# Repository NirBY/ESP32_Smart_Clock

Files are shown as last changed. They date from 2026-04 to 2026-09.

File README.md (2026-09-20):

# ESP32 Smart Clock

ESP32 smart clock project with an 8x32 MAX7219 LED matrix, AHT20/BMP280 indoor sensors, an NS4168 I2S audio amplifier module, and Home Assistant control through ESPHome.

For normal use, install the **ESPHome smart clock firmware** from `esphome-smart-clock.yaml`.

## Quick Start

1. Install the tested ESPHome version: `python -m pip install "esphome==2026.9.0"`.
2. Copy `secrets.example.yaml` to `secrets.yaml`.
3. Put your Wi-Fi and ESPHome API key in `secrets.yaml`.
4. Connect the ESP32 with a USB data cable.
5. Compile and upload:

   ```powershell
   cd C:\workspace\esp32_smart_clock
   esphome compile esphome-smart-clock.yaml
   esphome upload esphome-smart-clock.yaml
   ```

6. Add the discovered ESPHome device in Home Assistant.

If upload fails, hold **BOOT** while upload starts, then release **BOOT** when writing begins.

## Recover Wi-Fi from your phone

The clock already includes **ESP32 Smart Clock Fallback**, a password-protected
Wi-Fi hotspot and setup page. No Bluetooth, app, Home Assistant connection, or
USB cable is needed to change the router name/password.

1. Power the clock normally. If its configured Wi-Fi network cannot be reached
   (for example, after changing the router password), wait **90 seconds**.
   The fallback hotspot starts automatically; there is no button to press.
2. On your phone, open **Settings > Wi-Fi** and join
   **ESP32 Smart Clock Fallback**.
3. Enter the hotspot password: the value of `fallback_ap_password` in your
   private `secrets.yaml`. This is separate from your home Wi-Fi password.
   Public release builds use the example value `CHANGE_ME_FALLBACK_AP_PASSWORD`.
4. Accept **Stay connected / Use without Internet** if prompted. If the setup
   page does not open automatically, open **http://192.168.4.1/** in your browser
   (HTTP, not HTTPS). Temporarily turn off mobile data or a VPN if your phone
   keeps routing away from the clock.
5. Select your home **2.4 GHz** Wi-Fi network, or enter its name manually, enter
   its password, and press **Save**. The ESP32 board used here cannot join 5 GHz.
6. Allow the clock to connect, then reconnect your phone to your normal network.
   The fallback hotspot shuts down after connection. If the password is wrong,
   reconnect to the fallback hotspot and try again.

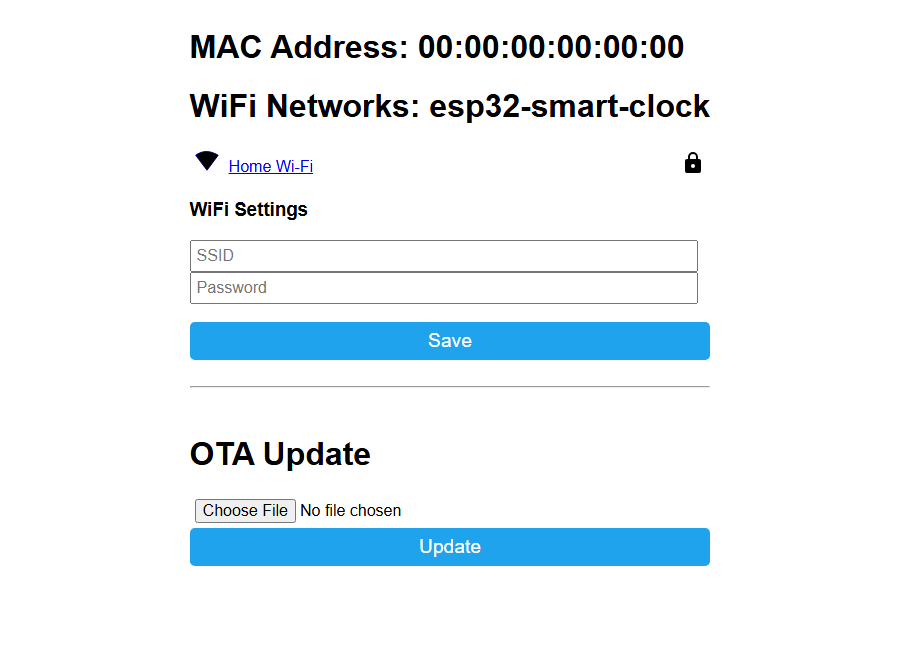
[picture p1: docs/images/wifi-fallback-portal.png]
ESPHome fallback Wi-Fi setup page


*Screenshot of the original ESPHome 2026.9.0 portal rendered locally with
example network data. Your available networks will differ.*

The portal saves the new credentials on the clock across restarts. Also update
`wifi_ssid` and `wifi_password` in your local `secrets.yaml` before the next USB
build/upload, so a future firmware installation does not restore stale values.
Changing Wi-Fi here does not change the Home Assistant API encryption key.

To test recovery without changing your router, temporarily flash a local build
with a nonexistent Wi-Fi SSID, wait 90 seconds, then follow the steps above.
Keep a copy of your correct local settings. Do not reset or erase the device.

Reference: [ESPHome captive portal documentation](https://esphome.io/components/captive_portal/).

## Firmware Updates

For a personalized clock, update from your local ESPHome YAML. This preserves
your private `secrets.yaml` and any local config edits:

```powershell
esphome run esphome-smart-clock.yaml --device 192.168.1.99
```

Replace `192.168.1.99` with the clock IP address.

The GitHub release update entity checks public release binaries. Those binaries
are built in GitHub Actions with `secrets.example.yaml`, so they are useful as
reference/recovery artifacts but are not the normal update path for a device
that needs your local Wi-Fi/API secrets.



The button imports a safe check/notify blueprint. It does not install public
GitHub firmware unless you explicitly enable that option.

## Calendar Agenda Announcements

Home Assistant can read today's events from a calendar, print a compact agenda
on the LED matrix, and optionally speak the same agenda through the clock
speaker. The automation can run every day at a selected time, from an
`input_button` helper, or both.



Create an `input_button` helper if you want a dashboard button, then import the
blueprint and select your calendar, clock speaker, and ESPHome display action.

## Tested software versions

| Component | Version |
|---|---|
| Clock firmware | 0.1.0-beta.14 |
| ESPHome | 2026.9.0 (see `ESPHOME_VERSION`) |
| PlatformIO Core (ESPHome dependency) | 6.1.19 |
| PlatformIO Core (separate Arduino builds) | 6.2.0 |
| Arduino PlatformIO platform | pioarduino 55.03.312 |
| Arduino-ESP32 / ESP-IDF | 3.3.12 / 5.5.5 |
| ESP32-A2DP | 1.8.11 |
| Adafruit AHTX0 / BMP280 / GFX | 2.0.6 / 3.0.0 / 1.12.6 |
| MD_MAX72XX | 3.5.1 |

The ESPHome firmware uses its own supported ESP-IDF toolchain. The Arduino
platform above is used for the separate hardware-test and Bluetooth builds.
Release CI installs the exact version in `ESPHOME_VERSION` and builds with
`secrets.example.yaml`; private local firmware binaries must not be published.

## Firmware Options

| Firmware | Use for | Home Assistant | Wi-Fi | Bluetooth music |
|---|---|---:|---:|---:|
| ESPHome smart clock | Clock, sensors, screen messages, alarm, Home Assistant speaker | Yes | Yes | No |
| Bluetooth speaker | Direct Bluetooth music from phone/PC | No | No | Yes |
| PlatformIO hardware test | Checking wiring and modules | No | No | No |

The ESP32 runs one firmware at a time. Flashing the Bluetooth speaker firmware replaces ESPHome. Flashing ESPHome again replaces the Bluetooth speaker firmware.

## Hardware Summary

- ESP32 30-pin dev board, CH340C, USB-C, HW-394 style board
- MAX7219 8x32 LED matrix
- NS4168 I2S Class-D audio amplifier module with speaker
- AHT20 + BMP280 I2C temperature, humidity, and pressure board
- 5V 3A USB-C power supply

Main pins:

| Function | ESP32 pin |
|---|---:|
| I2C SDA | GPIO21 |
| I2C SCL | GPIO22 |
| MAX7219 DIN | GPIO23 |
| MAX7219 CLK | GPIO18 |
| MAX7219 CS/LOAD | GPIO5 |
| I2S DATA | GPIO25 |
| I2S BCLK | GPIO26 |
| I2S LRCLK/WS | GPIO27 |

All module grounds must be connected together.

## Wiki

Detailed documentation was moved out of the README:

- [Wiki Home](docs/wiki/Home.md)
- [Hardware And Power](docs/wiki/Hardware-And-Power.md)
- [Install And Home Assistant](docs/wiki/Install-And-Home-Assistant.md)
- [Home Assistant Dashboard](docs/wiki/Home-Assistant-Dashboard.md)
- [Calendar And Announcements](docs/wiki/Calendar-And-Announcements.md)
- [Display Behavior](docs/wiki/Display-Behavior.md)
- [Audio And Music](docs/wiki/Audio-And-Music.md)
- [Logs And Troubleshooting](docs/wiki/Logs-And-Troubleshooting.md)
- [Development And Releases](docs/wiki/Development-And-Releases.md)

## Common Commands

Open logs over USB:

```powershell
esphome logs esphome-smart-clock.yaml --device COM5
```

Upload and keep logs open:

```powershell
esphome run esphome-smart-clock.yaml --device COM5
```

Upload an already compiled firmware over Wi-Fi by IP address:

```powershell
esphome upload esphome-smart-clock.yaml --device 192.168.1.99
```

Upload over Wi-Fi by IP address and keep logs open:

```powershell
esphome run esphome-smart-clock.yaml --device 192.168.1.99
```

For the separate Arduino builds, install PlatformIO 6.2.0 in its own environment
(ESPHome requires PlatformIO 6.1.19 in its environment):

```powershell
python -m venv .pio/core
.pio/core/Scripts/python.exe -m pip install "platformio==6.2.0"
```

Build the PlatformIO hardware test:

```powershell
.pio/core/Scripts/pio.exe run -e esp32dev
```

Build the Bluetooth speaker firmware:

```powershell
.pio/core/Scripts/pio.exe run -e bluetooth_speaker
```

## Notes

- Do not commit `secrets.yaml`; it is ignored by git.
- `GPIO5` is an ESP32 strapping pin. It is currently used for MAX7219 CS/LOAD, so avoid external pull-up/down effects on that pin.
- Hebrew MAX7219 font glyphs can be designed with [md_max72xx-font-designer](https://github.com/vasco65/md_max72xx-font-designer/tree/master).
- For audio noise or playback issues, see [Logs And Troubleshooting](docs/wiki/Logs-And-Troubleshooting.md) and [Audio And Music](docs/wiki/Audio-And-Music.md).

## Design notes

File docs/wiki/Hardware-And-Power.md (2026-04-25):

# Hardware And Power

## Hardware

- ESP32 30-pin dev board, CH340C, USB-C, HW-394 style board
- MAX7219 8x32 LED matrix board, usually four chained 8x8 modules
- NS4168 I2S Class-D audio amplifier module with speaker
- AHT20 + BMP280 I2C temperature, humidity, and pressure board
- 5V 3A USB-C power supply

## Pin Map

| Function | Module pin | ESP32 pin | Notes |
|---|---:|---:|---|
| I2C SDA | AHT20/BMP280 SDA | GPIO21 | Sensor board logic must be 3.3V-safe |
| I2C SCL | AHT20/BMP280 SCL | GPIO22 | Sensor board logic must be 3.3V-safe |
| SPI MOSI | MAX7219 DIN | GPIO23 | Use short wires |
| SPI CLK | MAX7219 CLK | GPIO18 | Use short wires |
| SPI CS | MAX7219 CS/LOAD | GPIO5 | Boot strap pin; keep external pull effects low |
| I2S DATA | NS4168 DIN | GPIO25 | Audio data out |
| I2S BCLK | NS4168 BCLK | GPIO26 | Audio bit clock |
| I2S L/R CLK | NS4168 LRC/WS | GPIO27 | Audio word select |

All module grounds must be connected together.

## Power

- Power the ESP32 through USB-C during programming.
- For normal use, use a stable 5V supply sized for the LED matrix and speaker. 5V 3A is a good starting point.
- MAX7219 VCC: 5V.
- NS4168 VCC: 3.0V-5.5V; this project uses 5V.
- AHT20/BMP280 VCC: 3V3, unless your exact sensor module explicitly supports 5V logic.
- Add a 470uF-1000uF electrolytic capacitor near the amplifier and LED matrix between 5V and GND if audio or display flickers.
- If the MAX7219 is unreliable from ESP32 3.3V logic, add a 3.3V-to-5V logic level shifter on DIN, CLK, and CS.

Do not connect an external 5V supply to VIN while the ESP32 is also powered from USB unless the board documentation says that exact board has safe power-path isolation.

## USB + VIN Safety

Do not assume it is safe to connect both USB from the PC and an external 5V supply to VIN at the same time.

Some ESP32 dev boards isolate USB 5V and VIN with a diode or power-path circuit. Many low-cost CH340/USB-C boards do not document this clearly, and back-feeding 5V into the PC USB port can damage the USB port, the ESP32 board, or the power supply.

Safer options:

- During programming: power the ESP32 from USB only, and disconnect external 5V from VIN.
- During full hardware testing: connect PC USB for data, power the LED matrix/amplifier from the external 5V supply, and connect all grounds together. Do not connect that external 5V to ESP32 VIN unless you have verified the board schematic.
- Best permanent setup: power the ESP32 from the same regulated 5V supply through its 5V/VIN pin only, and use OTA updates after the first flash.
- If you must use USB data and external 5V together, use a USB data-only cable or a USB power blocker so the PC 5V line is not connected.

## GPIO5 Note

`GPIO5` is used as MAX7219 CS/LOAD. It is an ESP32 strapping pin, so ESPHome warns about it at boot. The current hardware keeps it as-is. Avoid external pull-up or pull-down circuits on this pin that could affect boot mode.

## PSRAM Note

On PSRAM-enabled modules, `GPIO16` can be connected to internal PSRAM and may not be usable as a normal GPIO. The current HW-394 style board is treated as a normal ESP32 dev board with 4MB flash.

## Audio Amplifier Module

The actual I2S amplifier module used in this build is NS4168-based.

Datasheet:

https://www.chipsourcetek.com/Uploads/file/NS4168.pdf

Relevant module notes:

- I2S serial digital audio input.
- Working voltage: 3.0V-5.5V.
- Output power: 2.5W at 5V with a 4 ohm speaker.
- Automatic sampling-rate detection, advertised for 8kHz-96kHz.
- Built-in high-pass filter and protection features.
- Left/right channel selection may depend on the module `CTRL` pin wiring or board defaults.

If playback sounds like white noise, check I2S wiring first: `DIN`, `BCLK`, and `LRC/WS` must not be swapped. Also check whether the module exposes `CTRL`; if it does, the selected channel level may matter.

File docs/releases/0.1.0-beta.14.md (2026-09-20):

# ESP32 Smart Clock 0.1.0-beta.14

Updated the clock to ESPHome 2026.9.0 and documented phone-based Wi-Fi recovery
through **ESP32 Smart Clock Fallback**, including a screenshot of the original
portal rendered with example network data. The recovery timeout is explicitly
90 seconds.

## Software

- ESPHome 2026.9.0, native ESP-IDF 5.5.5 toolchain.
- pioarduino 55.03.312 / Arduino-ESP32 3.3.12 for the two Arduino variants.
- ESP32-A2DP 1.8.11; pinned current AHTX0 2.0.6, BMP280 3.0.0,
  GFX 1.12.6 and MD_MAX72XX 3.5.1.
- Separate PlatformIO environments: 6.1.19 for ESPHome's dependency and 6.2.0
  for Arduino builds. CI uses the same separation and the tracked ESPHome version.
- Replaced the reserved all-zero public example API key with a valid nonzero
  example key; personal builds must use a unique private key.
- CI collects firmware from both native ESP-IDF and legacy PlatformIO build paths.
- Windows documentation and editor paths migrated to C:\workspace\esp32_smart_clock.

## Validation

- ESPHome configuration validated and firmware compiled successfully.
- Hardware-test and Bluetooth-speaker firmware compiled successfully.
- ESPHome beta.14 flashed over USB to ESP32-D0WD-V3 revision 3.1; written data verified.
- Tested recovery with a deliberately nonexistent SSID: fallback AP started,
  the real portal and configuration endpoint returned HTTP 200, and saving
  correct Wi-Fi credentials restored the connection.
- Saved credentials survived a device restart.
- Final firmware rebuilt with the correct private local settings, flashed,
  and authenticated over the encrypted ESPHome API; 29 entities were enumerated.

## Known hardware limitation during validation

The attached unit still reports AHT20 and BMP280 communication failures, as it
already did before this upgrade. Sensor readings are not verified. Audio quality
and Bluetooth playback were not tested on the physical unit in this release.

## Updating

Build and install from your local YAML and private secrets for normal use.
Public release binaries are built in CI from `secrets.example.yaml`, with
placeholder Wi-Fi credentials and an example API key; they do not contain the
owner's private credentials. The fallback hotspot password in public builds is
`CHANGE_ME_FALLBACK_AP_PASSWORD`. Set up Wi-Fi through the portal, and configure
Home Assistant with the matching API key, or install your personalized build.

See [the README recovery guide](../../README.md#recover-wi-fi-from-your-phone).

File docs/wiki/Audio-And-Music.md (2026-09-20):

# Audio And Music

## Current Audio Design

Audio playback is configured for low-memory stability on a normal ESP32 without PSRAM. The stable ESPHome path is:

- WAV pipeline
- mono
- 16 kHz
- 16-bit samples
- `500ms` I2S output buffer
- `12000` media-player buffer
- mixer plus resampler speakers for separate media and announcement paths

This is best for TTS/announcements and simple Home Assistant audio. A 22.05 kHz test compiled, but failed at runtime with `i2s_audio.speaker: Not enough memory`, so the firmware intentionally stays at 16 kHz on this board. High-bitrate music streaming can still stress RAM; for direct music playback from phones/PCs, use the separate Bluetooth speaker firmware or an ESP32 board with PSRAM.

The ESPHome firmware uses:

- NS4168 I2S Class-D amplifier module
- `i2s_audio` speaker output
- `speaker` media player platform
- local `media/volume-beep.wav` for volume feedback and the optional hourly beep

## Music Casting Options

There are two supported music paths:

| Mode | Firmware | Works from | Notes |
|---|---|---|---|
| Wi-Fi via Home Assistant | `esphome-smart-clock.yaml` | Home Assistant media browser, automations, TTS, Music Assistant, local/online media URLs | Best option if this is mainly a Home Assistant clock |
| Bluetooth A2DP speaker | PlatformIO env `bluetooth_speaker` | Android, iPhone, Windows, macOS, Linux | Direct pairing like a Bluetooth speaker, but this firmware does not expose the HA sensors/display controls |

Direct Wi-Fi casting from every phone/PC app is not the same protocol:

- Android/PC "Cast" usually means Chromecast, which this ESP32 firmware does not implement.
- iPhone Wi-Fi speaker casting usually means AirPlay, which this ESP32 firmware does not implement.
- Spotify Connect also requires a different receiver stack.

For universal phone/PC playback, use the Bluetooth firmware. For Home Assistant-controlled playback, use the ESPHome firmware.

## Play Music Over Wi-Fi From Home Assistant

After flashing `esphome-smart-clock.yaml`, the device appears as a Home Assistant media player. You can play TTS, audio URLs, or media from Home Assistant-supported integrations.

Example using a direct MP3 URL:

```yaml
action: media_player.play_media
target:
  entity_id: media_player.esp32_smart_clock_speaker
data:
  media_content_id: "https://example.com/song.mp3"
  media_content_type: music
```

The exact `media_player` entity ID may be different in your Home Assistant. Use Developer Tools > States to confirm it.

## Local Beeps

Changing the `Speaker` media-player volume plays a short local beep so you can hear the effective level immediately.

If `Hourly Beep Enabled` is on, the same local beep also plays at the top of each hour. The switch is restored by Home Assistant and defaults to on. The firmware skips pending beeps while audio is already playing or announcing.

Hourly beep quiet hours are also configurable from Home Assistant:

- `Hourly Beep Quiet Hours Enabled` defaults to on.
- `Hourly Beep Quiet Start Hour` defaults to `22`.
- `Hourly Beep Quiet End Hour` defaults to `7`.
- Overnight ranges are supported, so `22` to `7` means no hourly beep from 22:00 until before 07:00.
- If start and end are the same hour, the quiet window is ignored.

The beep file is `media/volume-beep.wav`. It is embedded into the ESPHome firmware at compile time, so if you change it, compile and upload again.

The current beep format is:

- mono
- 16-bit PCM WAV
- 16 kHz
- short fade-in/fade-out
- silence at the beginning and end to reduce pop/noise

The firmware ignores volume-change beep requests during the first 15 seconds after boot. The hourly beep also waits until the device has been up for at least 15 seconds and is skipped during quiet hours. This avoids a boot-time beep when Home Assistant restores the media-player volume or time sync lands exactly on an hour.

## Speaker Wiring

| NS4168 module | ESP32 |
|---|---:|
| DIN | GPIO25 |
| BCLK | GPIO26 |
| LRC / WS | GPIO27 |
| VCC | 5V |
| GND | GND |

Speaker wires must connect only to the amplifier speaker output, not to the ESP32.

## Install Bluetooth Speaker Firmware

This turns the ESP32 into a direct Bluetooth music speaker named `ESP32 Smart Clock`.

This is an alternate firmware. It replaces ESPHome, so Home Assistant, Wi-Fi sensors, screen messages, and OTA updates will not work while this firmware is installed.

1. Install VS Code or Cursor.
2. Install the PlatformIO extension.
3. Open this folder.
4. Connect the ESP32 with a USB data cable.
5. In PlatformIO, choose environment `bluetooth_speaker`.
6. Click PlatformIO: Build.
7. Click PlatformIO: Upload.
8. Pair from Android, iPhone, Windows, macOS, or Linux with `ESP32 Smart Clock`.
9. Select it as the audio output device and play music.

Equivalent terminal commands:

```powershell
cd C:\workspace\esp32_smart_clock
# One-time setup; keep Arduino build tools separate from ESPHome.
python -m venv .pio/core
.pio/core/Scripts/python.exe -m pip install "platformio==6.2.0"
.pio/core/Scripts/pio.exe run -e bluetooth_speaker
.pio/core/Scripts/pio.exe run -e bluetooth_speaker -t upload
```

To go back to Home Assistant mode, flash `esphome-smart-clock.yaml` again from ESPHome.

## Audio Troubleshooting

If there is no sound:

- If logs show `Not enough memory` or `ESP_ERR_NO_MEM`, the stream is too heavy for the current no-PSRAM ESP32. Use lower-quality/mono media or the Bluetooth firmware.
- Check logs while playing audio.
- ESPHome does not expose the incoming stream size before playback starts. The firmware can report fast playback dropouts, but it cannot reject a stream early based on file size or bitrate.
- Fast media dropouts show `AUDIO ERR` on the matrix and fire the Home Assistant event `esphome.media_playback_failed`.
- Confirm the amplifier has 5V power.
- Confirm all grounds are common.
- Try a lower volume first.
- Add a 470uF-1000uF capacitor near the amplifier between 5V and GND.
- Some NS4168-style boards expose a `CTRL`, `SD`, or channel-select pin. If your board exposes it, check the board specs and pull it to the required level.

If audio is noisy:

- Keep I2S wires short.
- Add bulk capacitance near the amplifier.
- Check that `DIN`, `BCLK`, and `LRCLK/WS` are not swapped.
- Capture audio logs as described in [Logs And Troubleshooting](Logs-And-Troubleshooting.md).
- Confirm what format Home Assistant is sending. The current ESPHome speaker pipeline is tuned for low-memory 16 kHz mono playback.

Example automation trigger for playback failures:

```yaml
trigger:
  - platform: event
    event_type: esphome.media_playback_failed
```

## Actual Amplifier Module

The module used in this build is an NS4168-based I2S Class-D amplifier board.

Datasheet:

https://www.chipsourcetek.com/Uploads/file/NS4168.pdf

The datasheet / module information describes:

- NS4168 I2S digital audio amplifier
- I2S digital input
- 3.0V-5.5V working voltage
- 2.5W output power at 5V and 4 ohm load
- 8kHz-96kHz automatic sampling-rate detection
- built-in high-pass filter and protection mechanisms
- optional left/right channel behavior through `CTRL`

Because the module supports automatic 8kHz-96kHz sampling-rate detection, the current `16000 Hz` firmware output should be inside the supported range. If decoded audio logs show valid PCM, but the speaker output is still white noise, the next suspects are I2S format, channel selection, or wiring rather than only bitrate.

Useful log line from a known-good decode path should look like:

```text
Decoded audio has 1 channels, 16000 Hz sample rate, and 16 bits per sample
```

If you hear white noise while logs show valid decoded audio, test these next:

- verify `DIN`, `BCLK`, and `LRC/WS` wiring again
- try very short wires between ESP32 and the amplifier
- check whether `CTRL` is floating and whether it needs GND/VCC for the selected channel
- test `channel: left` and `channel: right` in `esphome-smart-clock.yaml`
- test a different I2S communication format only one change at a time

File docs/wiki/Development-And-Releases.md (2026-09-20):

# Development And Releases

## Windows + VS Code + PlatformIO Install

Use this if you want to work from VS Code on Windows.

Important: PlatformIO installs the PlatformIO firmwares in `platformio.ini`. The normal Home Assistant smart clock firmware is ESPHome, so install it from the VS Code terminal with the `esphome` command.

### 1. Install Tools

1. Install Python 3 from https://www.python.org/downloads/windows/.
2. During Python install, enable "Add python.exe to PATH".
3. Install VS Code from https://code.visualstudio.com/.
4. Open VS Code.
5. Open Extensions.
6. Install **PlatformIO IDE**.
7. Open a new VS Code terminal: Terminal > New Terminal.
8. Install ESPHome:

   ```powershell
   python -m pip install esphome
   ```

9. Verify the tools:

   ```powershell
   python --version
   pio --version
   esphome version
   ```

If `esphome` is not found, use:

```powershell
python -m esphome version
```

### 2. Open The Project

1. In VS Code, choose File > Open Folder.
2. Open:

   ```text
   C:\workspace\esp32_smart_clock
   ```

3. Wait for PlatformIO to load the project.
4. Connect the ESP32 with a USB data cable.
5. Check Windows Device Manager if needed. CH340 boards usually appear as a `USB-SERIAL CH340` COM port.

### 3. Install The Normal ESPHome Smart Clock Firmware

This is the recommended first install.

1. Edit `secrets.yaml` with your Wi-Fi and API key.
2. In the VS Code terminal, run:

   ```powershell
   cd C:\workspace\esp32_smart_clock
   esphome compile esphome-smart-clock.yaml
   esphome upload esphome-smart-clock.yaml
   ```

3. Choose the ESP32 COM port when ESPHome asks.
4. If upload fails, hold **BOOT** while upload starts, then release **BOOT** when writing begins.
5. After flashing, add `ESP32 Smart Clock` in Home Assistant under Settings > Devices & services.

After the first USB install, future ESPHome uploads can usually happen over Wi-Fi:

```powershell
cd C:\workspace\esp32_smart_clock
esphome upload esphome-smart-clock.yaml
```

If name discovery fails but you know the clock's IP address, upload directly:

```powershell
esphome upload esphome-smart-clock.yaml --device 192.168.1.99
```

To upload and immediately watch logs from that IP:

```powershell
esphome run esphome-smart-clock.yaml --device 192.168.1.99
```

Replace `192.168.1.99` with the IP from your router, Home Assistant device page,
or ESPHome logs. This still requires a previously flashed ESPHome firmware with
Wi-Fi and the ESPHome API working.

## Install The PlatformIO Hardware Test

This is only for checking the hardware wiring. It replaces the ESPHome firmware until you flash ESPHome again.

1. Install VS Code or Cursor.
2. Install the PlatformIO extension and ensure its Core version is at least 6.2.0.
3. Open this folder.
4. Connect the ESP32 with a USB data cable.
5. Click PlatformIO: Build.
6. Click PlatformIO: Upload.
7. Open Serial Monitor at 115200 baud.
8. If upload fails, hold BOOT while upload starts, then release when writing begins.

Equivalent terminal commands:

```powershell
cd C:\workspace\esp32_smart_clock
# One-time setup; keep Arduino build tools separate from ESPHome.
python -m venv .pio/core
.pio/core/Scripts/python.exe -m pip install "platformio==6.2.0"
.pio/core/Scripts/pio.exe run -e esp32dev
.pio/core/Scripts/pio.exe run -e esp32dev -t upload
pio device monitor -b 115200
```

## Current Firmware

`src/main.cpp` is a PlatformIO hardware test:

- scans I2C
- reads AHT20 humidity/temperature
- reads BMP280 temperature/pressure
- scrolls readings on the MAX7219 matrix
- plays a short I2S tone through the NS4168 amplifier/speaker

This test firmware does not connect to Wi-Fi or Home Assistant.

## PlatformIO Environments

`platformio.ini` includes:

- `esp32dev` - hardware test firmware from `src/main.cpp`
- `bluetooth_speaker` - Bluetooth A2DP speaker firmware from `src/bt_a2dp_sink.cpp`

Both environments use ESP32 HW-394 / WR-32 style board settings:

```ini
board_build.mcu = esp32
board_build.f_cpu = 240000000L
board_build.flash_size = 4MB
board_build.flash_mode = dio
board_upload.flash_size = 4MB
```

## Emulator / Simulation

You can use an emulator for partial testing, but not for full hardware verification.

Recommended simulator: **Wokwi**.

What you can reasonably test in Wokwi:

- ESP32 boot and serial logs
- basic Arduino/PlatformIO firmware logic
- GPIO wiring mistakes
- SPI wiring to a MAX7219-style LED matrix
- some I2C sensor behavior, depending on available Wokwi parts or custom simulation examples

What you should not trust an emulator to fully verify:

- NS4168 I2S amplifier audio quality
- real speaker volume/noise
- Bluetooth A2DP pairing/audio
- real Wi-Fi connection to your router
- Home Assistant discovery and OTA on your local network
- 5V/VIN/USB power safety
- level shifting problems between ESP32 3.3V logic and MAX7219 5V logic

Best use of simulation:

1. Simulate the PlatformIO hardware-test firmware first.
2. Confirm the code boots and the display/sensor logic is sane.
3. Build the ESPHome firmware locally with:

   ```powershell
   cd C:\workspace\esp32_smart_clock
   esphome compile esphome-smart-clock.yaml
   ```

4. Do the final verification on the real ESP32 hardware.

For this project, the emulator is a helpful pre-check, not a replacement for real hardware testing.

### Wokwi Notes

Wokwi supports ESP32 simulation and many common peripherals, including MAX7219 LED matrix modules. ESP32 I2S support is limited/in progress, so do not use Wokwi as proof that the NS4168 speaker wiring or audio playback is correct.

For ESPHome, the better "software-only" check is:

```powershell
esphome config esphome-smart-clock.yaml
esphome compile esphome-smart-clock.yaml
```

ESPHome also has a `host` platform for running some ESPHome configs on a desktop computer, but many real hardware components are unavailable there. This project uses real ESP32 hardware features, so `host` is useful only for limited API/software experiments, not for full clock validation.

## GitHub Releases

The repository includes a GitHub Actions workflow that builds and verifies firmware when you push a version tag.

The workflow:

- creates CI-only dummy `secrets.yaml` from `secrets.example.yaml`
- validates and compiles `esphome-smart-clock.yaml`
- builds the PlatformIO hardware test firmware
- builds the PlatformIO Bluetooth speaker firmware
- stamps the ESPHome project version from the release tag
- uploads all firmware binaries to a GitHub Release
- uploads `esphome-smart-clock.ota.md5` and `firmware-manifest.json` for public GitHub firmware checks
- updates the `firmware-latest` branch with the OTA binary, MD5, and manifest used by the disabled-by-default public update entity

Create a new release:

```powershell
git tag v1.0.0
git push origin v1.0.0
```

Use a new tag for each release, for example `v1.0.1`, `v1.1.0`, or `v2.0.0`.

The normal smart-clock update assets are:

- `esphome-smart-clock.ota.bin` - Home Assistant/ESPHome OTA update binary
- `esphome-smart-clock.factory.bin` - USB/recovery binary
- `esphome-smart-clock.ota.md5` - checksum used by ESPHome HTTP OTA
- `firmware-manifest.json` - release copy of the manifest used by the `Firmware Update` entity in Home Assistant

The firmware reads the latest manifest from the raw `firmware-latest` branch:

`https://raw.githubusercontent.com/NirBY/ESP32_Smart_Clock/firmware-latest/firmware-manifest.json`

For normal personalized clocks, install updates from your local ESPHome YAML by
USB or by IP. That preserves `secrets.yaml` and any local YAML edits. The GitHub
manifest/update entity points at public release binaries built in GitHub Actions
with `secrets.example.yaml`.

## GitHub Public Firmware Check Flow

The update system has two halves:

- GitHub Actions builds and publishes release assets.
- GitHub Actions mirrors the Home Assistant OTA files to the `firmware-latest` branch.
- Home Assistant can notify you that a public release exists.

The ESP32 does not poll GitHub and self-update silently. It exposes a normal
Home Assistant `update` entity. The safe default is notification only. For a
personalized device, update by IP from your local ESPHome YAML instead:

```powershell
esphome upload esphome-smart-clock.yaml --device 192.168.1.99
```

The device uses the raw `firmware-latest` branch instead of
`releases/latest/download`. GitHub release-download URLs return very large
redirect/security headers, which can overflow the ESP32 HTTP client buffer.
Raw GitHub files keep the update check small and predictable.

```mermaid
flowchart TD
  A["Push a version tag, for example v0.1.0-beta.8"] --> B["GitHub Actions release workflow starts"]
  B --> C["Workflow validates ESPHome config and compiles firmware"]
  C --> D["Workflow builds extra PlatformIO test firmwares"]
  D --> E["Workflow creates release assets"]
  E --> F["GitHub Release assets"]
  E --> G["firmware-latest branch"]
  G --> H["esphome-smart-clock.ota.bin"]
  G --> I["esphome-smart-clock.ota.md5"]
  G --> J["firmware-manifest.json"]
  J --> K["ESPHome Firmware Update entity checks latest manifest"]
  K --> L["Home Assistant can show update available"]
  L --> M["Blueprint creates a notification by default"]
  M --> N["User runs local ESPHome upload by IP"]
  N --> O["ESPHome compiles with local secrets.yaml"]
  O --> P["ESPHome uploads OTA to the clock"]
```

What each release file does:

- `firmware-latest/esphome-smart-clock.ota.bin` is the file installed by Home Assistant/ESPHome OTA.
- `firmware-latest/esphome-smart-clock.ota.md5` is the checksum used to verify the downloaded OTA binary.
- `firmware-latest/firmware-manifest.json` tells the ESPHome update entity the latest version, OTA URL, checksum, and release URL.
- `esphome-smart-clock.factory.bin` is only for USB first flash or recovery. It is not used by the Home Assistant update entity.

The firmware uses this manifest URL:

```text
https://raw.githubusercontent.com/NirBY/ESP32_Smart_Clock/firmware-latest/firmware-manifest.json
```

The release workflow stamps `esphome.project.version` from the Git tag. For a
tag named `v0.1.0-beta.8`, the firmware reports version `0.1.0-beta.8`.
Home Assistant compares that installed version with the manifest version to
decide whether `update.esp32_smart_clock_firmware_update` is `on`.

Requirements:

- The GitHub update entity is disabled by default in current firmware because
  public binaries do not contain your local secrets or local YAML edits.
- The ESP32 needs internet access to GitHub over HTTPS to check/install public
  release binaries.
- Home Assistant must be connected to the ESPHome device.
- If Home Assistant generated a different entity ID, select that entity in the
  blueprint or edit the automation YAML.

Important: do not use automatic `update.install` for a normal personalized
clock. It installs the public binary. Use local OTA by IP for your real device.

## Verify Latest Packages Workflow

The `Verify latest packages` workflow checks current ESPHome and PlatformIO packages, builds the firmware, and pushes a manual-review branch with the verification report.

The workflow is intentionally not a release workflow. It verifies package updates and asks for manual review before anything is merged.

## ESPHome Upgrade PR Workflow

The `ESPHome Upgrade PR` workflow checks PyPI for the latest stable ESPHome release every Monday and can also be run manually.

It uses `ESPHOME_VERSION` as the last verified ESPHome version. When a newer ESPHome version is found, the workflow:

- installs that exact ESPHome version
- validates `esphome-smart-clock.yaml`
- compiles the ESPHome firmware
- builds the PlatformIO hardware test firmware
- builds the PlatformIO Bluetooth speaker firmware
- updates `ESPHOME_VERSION`
- writes `.github/reports/esphome-upgrade.md`
- opens a pull request for review

This keeps upgrades safe: ESPHome changes are tested first, then merged and released manually.

If GitHub Actions cannot create the PR, enable this repository setting:

`Settings` > `Actions` > `General` > `Workflow permissions`

Enable:

- `Read and write permissions`
- `Allow GitHub Actions to create and approve pull requests`

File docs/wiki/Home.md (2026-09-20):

# ESP32 Smart Clock Wiki

This wiki contains the detailed project documentation. Keep `README.md` short and link here for the full setup and troubleshooting notes.

## Pages

- [Hardware And Power](Hardware-And-Power.md)
- [Install And Home Assistant](Install-And-Home-Assistant.md)
- [Home Assistant Dashboard](Home-Assistant-Dashboard.md)
- [Calendar And Announcements](Calendar-And-Announcements.md)
- [Display Behavior](Display-Behavior.md)
- [Audio And Music](Audio-And-Music.md)
- [Logs And Troubleshooting](Logs-And-Troubleshooting.md)
- [Development And Releases](Development-And-Releases.md)

## Firmware Options

For normal use, install the **ESPHome smart clock firmware** from `esphome-smart-clock.yaml`.

| Firmware | Use for | Home Assistant | Wi-Fi | Bluetooth music |
|---|---|---:|---:|---:|
| ESPHome smart clock | Clock, sensors, screen messages, alarm, Home Assistant speaker | Yes | Yes | No |
| Bluetooth speaker | Direct Bluetooth music from phone/PC | No | No | Yes |
| PlatformIO hardware test | Checking wiring and modules | No | No | No |

The ESP32 runs one firmware at a time. Flashing the Bluetooth speaker firmware replaces ESPHome. Flashing ESPHome again replaces the Bluetooth speaker firmware.

If this is your first install, start with **ESPHome smart clock**.

## Main Files

- `esphome-smart-clock.yaml` - normal Home Assistant smart clock firmware.
- `platformio.ini` - PlatformIO environments for hardware test and Bluetooth speaker firmware.
- `src/main.cpp` - PlatformIO hardware test firmware.
- `src/bt_a2dp_sink.cpp` - Bluetooth speaker firmware.
- `media/volume-beep.wav` - local volume feedback beep used by ESPHome.
- `secrets.example.yaml` - template for private ESPHome secrets.

## Quick Commands

Compile ESPHome:

```powershell
cd C:\workspace\esp32_smart_clock
esphome compile esphome-smart-clock.yaml
```

Upload ESPHome:

```powershell
esphome upload esphome-smart-clock.yaml
```

Upload ESPHome over Wi-Fi by IP address:

```powershell
esphome upload esphome-smart-clock.yaml --device 192.168.1.99
```

Open ESPHome logs:

```powershell
esphome logs esphome-smart-clock.yaml --device COM5
```

Build PlatformIO hardware test:

```powershell
.pio/core/Scripts/pio.exe run -e esp32dev
```

Build Bluetooth speaker firmware:

```powershell
.pio/core/Scripts/pio.exe run -e bluetooth_speaker
```

For the isolated PlatformIO environment setup, see [the README](../../README.md#common-commands).

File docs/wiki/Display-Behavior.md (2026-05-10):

# Display Behavior

The display follows a fixed 7-rule spec. Anything not covered by these rules falls back to the clock.

## Clock Display Logic

1. **Default:** show the clock. Time is synced from Home Assistant as soon as the native API connects, with SNTP kept as an internet fallback refreshed every `1h`. When Wi-Fi connects, the firmware immediately restarts SNTP and retries every `15 seconds` until time becomes valid. Before time is valid, the display shows `SYNC`, `NO WIFI`, or `NO NET` instead of staying on `--:--`, unless `Show System Alerts` is disabled. The `Time Format` selector chooses either `HH:MM:SS` or the larger long-distance `HH:MM` view with a blinking colon. The fallback/default format is `HH:MM`.
2. **Screen message from Home Assistant:** show the message for `10 seconds` by default, then return to the clock. The duration is configurable with `Screen Message Seconds`. Sent via the `esphome.esp32_smart_clock_show_message` action or by writing the `Screen Message` text entity.
3. **Indoor sensors:** every `30 seconds` by default, show temperature and humidity for `3 seconds` by default. Both values are configurable from Home Assistant. The matrix uses a fixed non-scrolling layout like `24°C 57%`; if data is missing, it shows `00°C 00%`. Barometric pressure is still exposed to Home Assistant, but it is not shown on the LED matrix.
4. **Music / TTS:** while the speaker is active, show a label (`MUSIC` for media playback, `SPEAKER` for TTS/announcements). The label clears immediately on pause / idle / turn-off, and is hard-capped at `10 seconds` by default if no clear event arrives. If media starts and fails quickly, show `AUDIO ERR` for `5 seconds`. The normal cap is configurable with `Media Message Seconds`.
5. **Wi-Fi disconnected:** every `30 seconds` by default, show `NO WIFI` for `3 seconds` by default until Wi-Fi recovers. Both values are configurable from Home Assistant.
6. **Date and day:** at the top of every hour, show day-of-week and date for `3 seconds` by default. The duration is configurable with `Date Message Seconds`. If `Hourly Beep Enabled` is on and the current hour is outside the configured quiet window, the clock also queues the local beep at the same time.
7. **Invalid or missing data:** if any branch above has bad / `NaN` / not-yet-valid data (NTP not synced, sensor read failed, empty message, etc.), that branch is skipped and the clock is shown instead.

## Display Priority Order

Multiple events can be active at the same time. The display lambda checks branches in this fixed order; the first match wins:

1. `text_message` - Home Assistant message (`Screen Message Seconds`)
2. `media_message` - `MUSIC` / `SPEAKER` (`Media Message Seconds`)
3. `system_alert_message` - rotating startup/health alerts (`System Alert Seconds`)
4. `wifi_alert` - legacy `NO WIFI` alert (`Wi-Fi Alert Seconds`)
5. `date_message` - `Day DD/MM` (`Date Message Seconds`)
6. `sensor_message` - `temp humidity` (`Sensor Message Seconds`)
7. Default clock - selected `Time Format` (`HH:MM:SS` or larger `HH:MM`)

This is why a Home Assistant message hides a sensor screen, but a sensor screen never hides a message.

## Temporary Screens

| Trigger | Display | Duration | Source in `esphome-smart-clock.yaml` |
|---|---|---:|---|
| `esphome.esp32_smart_clock_show_message` action or `Screen Message` text entity | message text | `Screen Message Seconds` (default 10 s) | sets `text_message_until` in `api.actions.show_message` and `text.set_action` |
| Music playback starts | `MUSIC` | `Media Message Seconds` (default 10 s), cleared on pause/idle/off | `media_player.on_play` sets `media_message_until` |
| TTS / announcement starts | `SPEAKER` | `Media Message Seconds` (default 10 s), cleared on pause/idle/off | `media_player.on_announcement` sets `media_message_until` |
| Music playback starts then stops quickly | `AUDIO ERR` | 5 s | `media_player.on_idle` detects a fast media dropout and fires `esphome.media_playback_failed` |
| Music pauses, idles, or turns off | returns to clock | immediately | `on_pause` / `on_idle` / `on_turn_off` clear `media_message_until` |
| Startup time sync | `SYNC`, then `NO NET` if retries continue | `System Alert Seconds` every `System Alert Interval Seconds` | Wi-Fi `on_connect` and a 15-second retry loop restart SNTP until time is valid |
| Wi-Fi disconnected | `NO WIFI` | `System Alert Seconds` / `Wi-Fi Alert Seconds` | system alert rotation and the legacy Wi-Fi alert both require `Show System Alerts` |
| Top of each hour | `Day DD/MM` plus optional local beep | `Date Message Seconds` (default 3 s) | `time.on_time` with `seconds: 0, minutes: 0` sets `date_message_until` and queues the hourly beep when `Hourly Beep Enabled` is on and quiet hours do not apply |
| Indoor sensors | fixed `temp humidity`, for example `24°C 57%`; missing data shows `00°C 00%` | `Sensor Message Seconds` every `Sensor Message Interval Seconds` | dynamic `interval: 1s` check sets `sensor_message_until`; the display uses a fixed non-scrolling pixel layout |
| Alarm time reached | `ALARM` | `Alarm Message Seconds` (default 10 s) | `alarm_triggered` script sets `text_message_until` |
| System health alert | `NO SENSOR`, `NO AHT`, `NO BMP`, `NO SPK`, `LOW PWR`, `NO NET`, or `NO WIFI` | `System Alert Seconds` every `System Alert Interval Seconds` | dynamic alert rotation, enabled by the `Show System Alerts` switch. Sensor alerts use stale-update detection: if AHT20 or BMP280 stops publishing for about `75 seconds`, the matching alert is shown and a warning is logged. |
| Invalid / missing data on any branch | clock | immediately | each branch only renders after its own validity check; otherwise control falls through to the clock |

## Rendering And Hardware Notes

Short English/number messages use a custom 3x7 pixel renderer that spreads the text across all 32 columns. Longer supported messages scroll across the full matrix.

Hebrew screen messages use the `Noto Sans Hebrew` font. Short Hebrew messages are spread across the full matrix, and long Hebrew messages scroll from right to left.

Display brightness can be changed from Home Assistant with the `Display Brightness` number entity. `0` is dimmest, `15` is brightest.

Brightness changes are sent directly to the MAX7219 chips at runtime and are also re-applied after boot when the restored Home Assistant value is available.

Temporary display timings can also be changed from Home Assistant. The ESPHome firmware exposes number entities for `System Alert Seconds`, `System Alert Interval Seconds`, `Screen Message Seconds`, `Media Message Seconds`, `Alarm Message Seconds`, `Wi-Fi Alert Seconds`, `Wi-Fi Alert Interval Seconds`, `Date Message Seconds`, `Sensor Message Seconds`, and `Sensor Message Interval Seconds`. These values are restored after reboot.

The `Time Format` selector is restored after reboot. `HH:MM:SS` keeps the compact seconds display, while `HH:MM` removes seconds so the hour and minute digits can be drawn wider for better readability from far away. In the `HH:MM` format, the colon blinks once per second. If Home Assistant has no restored value yet, the firmware starts from `HH:MM`.

`Show System Alerts` is the Home Assistant checkbox that enables or skips matrix health warnings. `Speaker Connected` is a manual checkbox because the I2S amplifier/speaker wiring has no detection pin; turn it off to rotate a `NO SPK` alert. `Hourly Beep Enabled` controls whether the local beep plays at the top of each hour, and the quiet-hours controls suppress it during a configured hour range such as `22:00` to `07:00`.

## Song Name Limitation

The ESPHome `media_player: speaker` platform does not surface track-title metadata to the firmware, so the MAX7219 only ever shows the static labels `MUSIC` (for media playback) and `SPEAKER` (for TTS / announcements).

If you want the song title on the matrix, push it from a Home Assistant automation as a screen message:

```yaml
action: esphome.esp32_smart_clock_show_message
data:
  message: "{{ state_attr('media_player.esp32_smart_clock_speaker', 'media_title') }}"
```

That will show for `Screen Message Seconds` and then return to the clock, like any other screen message.

## Basic Emoji

English screen messages support a small set of monochrome 5x7 emoji-style icons. These are hand-drawn for the 8x32 LED matrix, not full color emoji fonts:

`❤️`, `💛`, `😀`, `🙂`, `🙁`, `😢`, `⭐`, `✅`, `✓`, `❌`, `✕`, `⚠️`, `🔔`, `♪`, `🎵`, `☀️`, `🌙`, `🔥`, `👍`, `📅`, `📆`

Unsupported emoji fall back to the ESPHome font renderer and may log `Codepoint ... not found in font`. Add only icons that need to be readable on the matrix; full emoji fonts are too large and most emoji do not survive well at 5x7 pixels.

## Reset Behavior

The display returns to the clock immediately when any of these happens:

- `esphome.esp32_smart_clock_clear_message` is called, or `Screen Message` is set to an empty string.
- The media player fires `on_pause`, `on_idle`, or `on_turn_off`.
- A temporary screen's data becomes invalid (`NaN` sensor read, empty message, NTP not yet valid). The matching branch is skipped and control falls through to the clock.
- All temporary timeouts have expired and no event is currently active.

## Hebrew Text

Hebrew is supported for Home Assistant screen messages.

Example:

```yaml
action: esphome.esp32_smart_clock_show_message
data:
  message: "שלום"
```

Limitations:

- The MAX7219 matrix is only 8 pixels high, so Hebrew is readable but small.
- Complex Hebrew shaping, nikud, and mixed Hebrew/English sentence layout are not handled.

## Text Does Not Use All LEDs

For the ESPHome firmware, the default clock and supported English/number messages are drawn across the full 8x32 matrix.

If supported text still appears on only part of the display, check the number of MAX7219 modules:

- Four 8x8 modules: keep `num_chips: 4`.
- One 8x8 module: change `num_chips: 1`.

In `esphome-smart-clock.yaml`:

```yaml
display:
  - platform: max7219digit
    num_chips: 4
```

If the text appears on only part of the display:

- Check DIN, CLK, CS wiring.
- Check that every MAX7219 module has 5V and GND.
- Check module direction. Many 8x32 boards have an input side and output side.
- Try `rotate_chip`, `reverse_enable`, or wiring from the other end if the display is mirrored or shifted.

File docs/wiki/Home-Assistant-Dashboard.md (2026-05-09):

# Home Assistant Dashboard

## What ESPHome Can And Cannot Control

ESPHome can organize Home Assistant by assigning entities to logical sub-devices
and by marking settings as configuration entities.

ESPHome cannot add custom explanatory text under each control in Home Assistant's
stock device page. That page is generated by Home Assistant. The best place for
friendly explanations is a dashboard card.

## Logical Devices

The firmware exposes these logical Home Assistant devices:

| Device | Purpose |
| --- | --- |
| ESP32 Smart Clock Display | Matrix brightness, time format, manual message text, and display timing controls. |
| ESP32 Smart Clock Alarm | Alarm enable, hour, minute, and alarm message duration. |
| ESP32 Smart Clock Audio | Speaker playback, speaker wiring hint, hourly beep, quiet hours, and media label duration. |
| ESP32 Smart Clock System | Startup, Wi-Fi, network, sensor, speaker, power alert controls, and GitHub release firmware updates. |
| ESP32 Smart Clock Sensors | AHT20 and BMP280 readings. |

Most settings are also marked as Home Assistant `config` entities. That keeps
the normal device page cleaner while still leaving real controls and readings
easy to find.

## Dashboard Template

Use `docs/home-assistant-dashboard.yaml` as a ready-to-paste Home Assistant
dashboard view. It uses only built-in Home Assistant cards:

- Markdown cards for the explanations Home Assistant cannot show below controls
  on the generated device page.
- Entity cards for quick glance controls.
- Entities cards grouped by Display, Alarm, Audio, System Alerts, Firmware Checks, and Sensors.

If Home Assistant generated different entity IDs on your system, edit the YAML
entity IDs after pasting it into the dashboard editor.

## Add It In Home Assistant

1. Open Home Assistant.
2. Go to Settings > Dashboards.
3. Create a new dashboard or open an existing dashboard.
4. Choose Edit dashboard.
5. Open the raw YAML editor.
6. Paste the contents of `docs/home-assistant-dashboard.yaml`.
7. Save.

For a single-card workflow, you can also go to the device page and use
Add to Dashboard, but Home Assistant chooses the generated card layout there.
The YAML template gives a cleaner, intentional control surface.

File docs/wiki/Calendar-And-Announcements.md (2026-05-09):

# Calendar And Announcements

The calendar agenda blueprint lets Home Assistant read today's events, show a
compact agenda on the ESP32 Smart Clock matrix, and optionally speak the agenda
through the clock speaker.

Import the blueprint:



The blueprint file is:

`docs/blueprints/automation/esp32_smart_clock_calendar_agenda.yaml`

## What It Does

- Calls `calendar.get_events` for today, from `00:00` to `23:59:59`.
- Builds a short matrix message like `Today: 09:00 Work; 18:30 Dinner`.
- Sends that message to `esphome.esp32_smart_clock_show_message`.
- Optionally calls `tts.speak` and plays the spoken agenda on the clock speaker.
- Runs from a daily time trigger, an `input_button` helper, or both.

## Required Entities

Select these when creating the automation from the blueprint:

| Blueprint input | Example | Purpose |
|---|---|---|
| Calendar | `calendar.family` | Source for today's events |
| Clock display action | `esphome.esp32_smart_clock_show_message` | Prints the agenda on the matrix |
| TTS provider | `tts.home_assistant_cloud` | Converts the agenda to speech |
| Clock speaker | `media_player.esp32_smart_clock_speaker` | Plays the spoken agenda |
| Manual run input button | `input_button.esp32_smart_clock_today_events` | Optional dashboard/manual trigger |

Entity IDs can be different on your Home Assistant system. Use Developer Tools >
States to confirm the exact IDs.

## Run At A Specific Time

Keep **Run every day at a specific time** enabled and choose **Daily agenda
time**. For example, set it to `07:30:00` for a morning agenda.

If you only want a manual button, turn **Run every day at a specific time** off.

## Run From A Button

Create a helper:

1. Open Home Assistant.
2. Go to Settings > Devices & services > Helpers.
3. Create helper.
4. Choose Button.
5. Name it `ESP32 Smart Clock Today Events`.
6. Select that input button in the blueprint.

You can add the helper button to any dashboard. Pressing it runs the same
calendar display and TTS action immediately.

If you do not want a manual button, leave the default dummy
`input_button.esp32_smart_clock_today_events` value. The scheduled trigger still
works, and the missing helper simply never fires a manual trigger.

## Display And TTS Options

- **Show events on the clock display** controls the LED matrix message.
- **Speak events with TTS** controls whether Home Assistant speaks the agenda.
- **Maximum events** limits how many events are printed and spoken.
- **Display prefix** defaults to `Today:`.
- **No events** messages can be customized separately for display and speech.

The display is intentionally compact because the matrix is only 8x32 pixels. For
long event names, the firmware scrolls the message.

## Notes

- The speaker pipeline is tuned for low-memory TTS and announcements. This is a
  better fit than high-quality music streaming.
- If the speaker is already busy, ESPHome may reject or interrupt audio
  depending on Home Assistant timing.
- Calendar event details come from Home Assistant, so permissions and calendar
  integration setup are handled there.

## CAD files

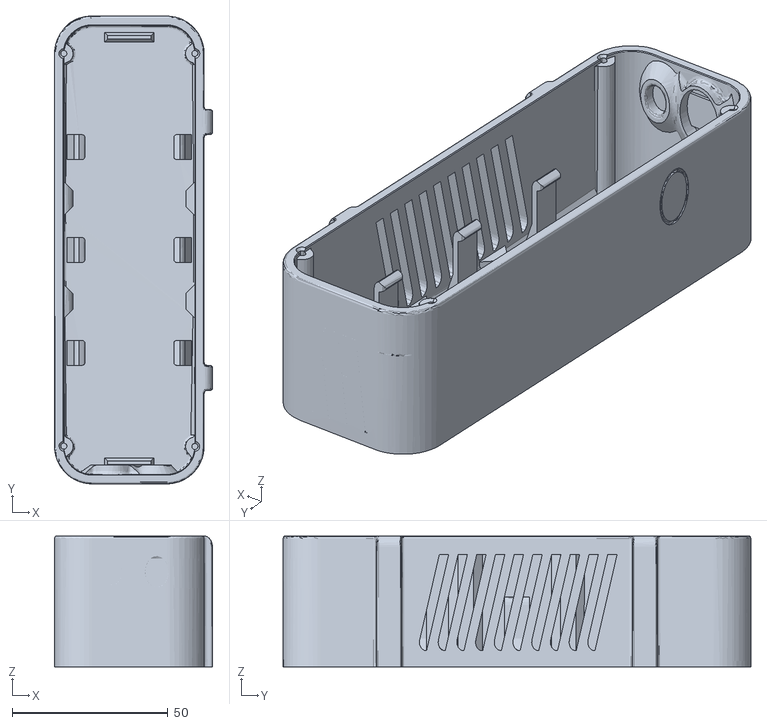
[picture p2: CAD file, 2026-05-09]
ESP32_Smart_Clock_3D_Design/ESP32_Smart_Clock_final_base.stl
50.7 x 150.0 x 42.0

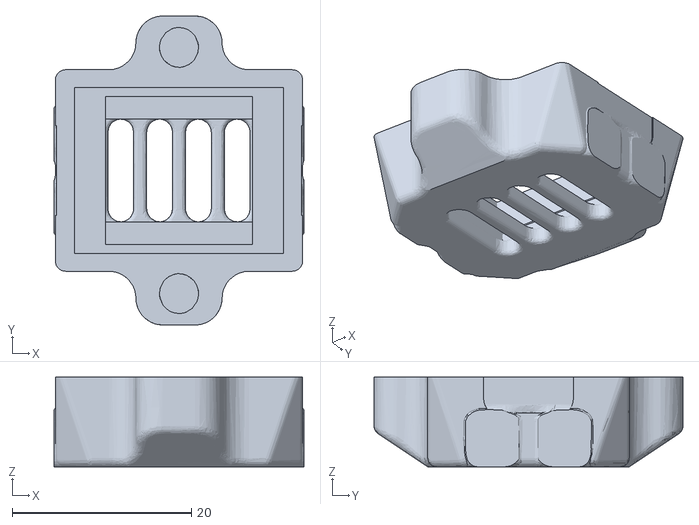
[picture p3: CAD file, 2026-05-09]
ESP32_Smart_Clock_3D_Design/ESP32_Smart_Clock_final_sensor_cover.stl
27.9 x 34.5 x 10.00

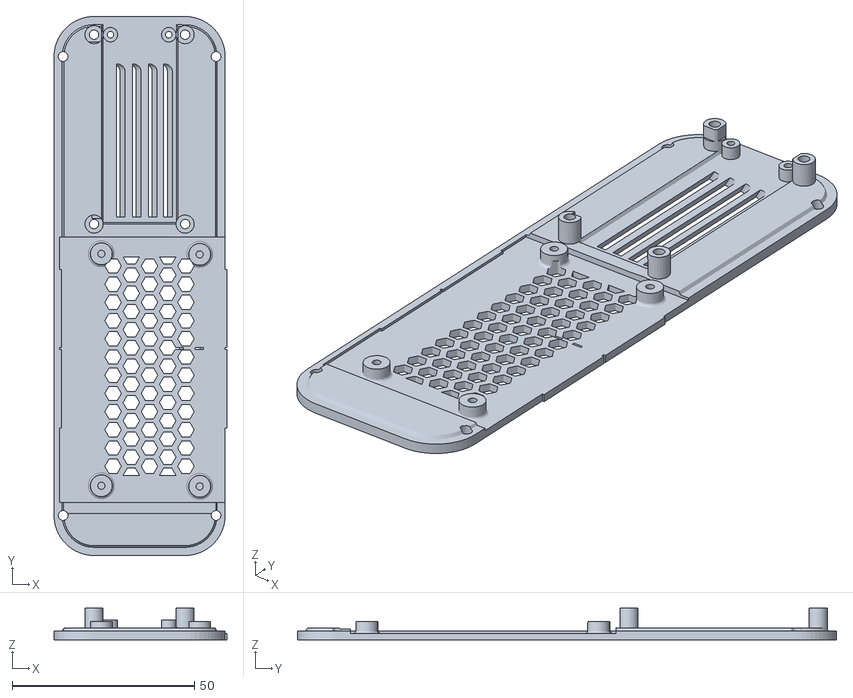
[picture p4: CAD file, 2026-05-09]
ESP32_Smart_Clock_3D_Design/ESP32_Smart_Clock_final_cover.stl
47.5 x 148.0 x 8.70

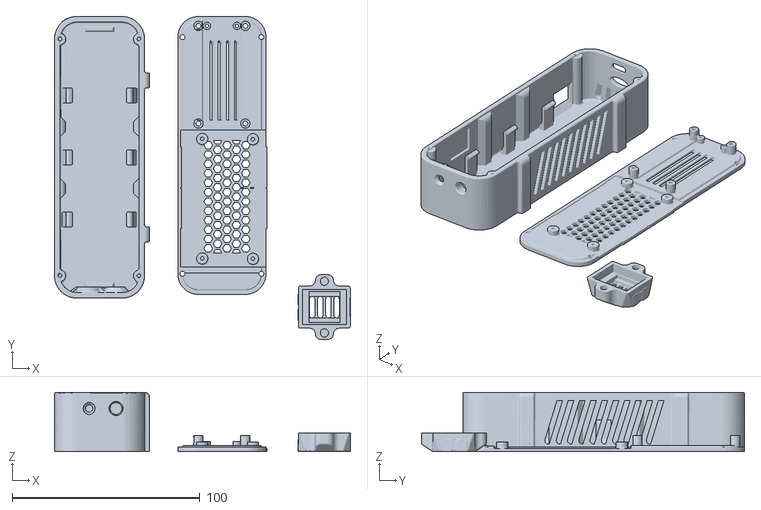
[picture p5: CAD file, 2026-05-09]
ESP32_Smart_Clock_3D_Design/ESP32_Smart_Clock_final.stl
157.7 x 172.0 x 31.6

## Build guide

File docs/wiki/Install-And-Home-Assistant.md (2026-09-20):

# Install And Home Assistant

## First-Time Install With ESPHome

Use this for the normal smart clock firmware.

### 1. Install The ESPHome Tool

On Windows, open PowerShell and run:

```powershell
python -m pip install esphome
```

Verify it installed:

```powershell
esphome version
```

If `esphome` is not found, try:

```powershell
python -m esphome version
```

### 2. Configure Wi-Fi

Create your private `secrets.yaml` from the dummy example, then edit it:

```powershell
cd C:\workspace\esp32_smart_clock
Copy-Item secrets.example.yaml secrets.yaml
```

Set your real Wi-Fi name and password:

```yaml
wifi_ssid: "YOUR_WIFI_NAME"
wifi_password: "YOUR_WIFI_PASSWORD"
fallback_ap_password: "choose-a-password"
api_encryption_key: "paste-the-key-generated-by-esphome"
```

For `api_encryption_key`, the easiest path is to create a temporary ESPHome device in Home Assistant and copy the generated key, or use any valid ESPHome API encryption key.

Do not commit `secrets.yaml`. It is ignored by git. Only `secrets.example.yaml` should be pushed to GitHub.

### 3. Connect USB

1. Connect the ESP32 to the PC with a USB data cable.
2. Use USB power only while flashing.
3. If the LED matrix and speaker need external 5V during testing, keep grounds connected, but do not connect external 5V to VIN while USB is connected unless your exact ESP32 board safely supports it.

### 4. Compile And Upload

Run:

```powershell
cd C:\workspace\esp32_smart_clock
esphome compile esphome-smart-clock.yaml
esphome upload esphome-smart-clock.yaml
```

When ESPHome asks, choose the USB serial port.

If upload fails, hold **BOOT** while upload starts, then release **BOOT** when writing begins.

### 5. Add To Home Assistant

1. Wait for the ESP32 to reboot.
2. It should connect to the Wi-Fi from `secrets.yaml`.
3. In Home Assistant, open Settings > Devices & services.
4. Add the discovered `ESP32 Smart Clock` ESPHome device.
5. Enter the API encryption key if Home Assistant asks.
6. Open the ESPHome integration device settings and enable "Allow the device to perform Home Assistant actions" if you want alarm events to trigger Home Assistant automations.

## Future Updates Over Wi-Fi

After the first USB flash, ESPHome OTA updates usually work over Wi-Fi.

From PowerShell:

```powershell
cd C:\workspace\esp32_smart_clock
esphome upload esphome-smart-clock.yaml
```

ESPHome will upload wirelessly if the device is online. If OTA fails or the device is offline, connect USB and upload again.

If mDNS discovery does not find `esp32-smart-clock.local`, upload directly to
the device IP address:

```powershell
esphome upload esphome-smart-clock.yaml --device 192.168.1.99
```

To upload and keep the live log open from that IP:

```powershell
esphome run esphome-smart-clock.yaml --device 192.168.1.99
```

Replace `192.168.1.99` with the current IP shown in your router, Home Assistant
device page, or ESPHome logs. This is still an OTA update, so it works only after
the first USB flash and only when the ESPHome API is reachable on the network.

From Home Assistant:

1. Install the ESPHome add-on if it is not installed.
2. Open ESPHome.
3. Import or create the `esp32-smart-clock` device.
4. Use the same YAML from `esphome-smart-clock.yaml`.
5. Click Install.
6. Choose Wirelessly for OTA updates, or USB/serial for first install.

## Home Assistant Control

For Home Assistant, use `esphome-smart-clock.yaml` with ESPHome. It exposes:

- `Temperature`, `Humidity`, and `Pressure` sensors
- `Screen Message` text entity
- `Display Brightness` number entity, range `0`-`15`
- display timing number entities for message/media/alarm/Wi-Fi/date/sensor screen durations and periodic intervals
- `Speaker` media player entity for Home Assistant TTS/audio
- `Hourly Beep Enabled` switch and quiet-hours controls for playing the local beep at the top of each hour
- disabled-by-default `Firmware Update` update entity for public GitHub release firmware
- `Alarm Enabled`, `Alarm Hour`, and `Alarm Minute` entities as alarm controls
- an `esphome.alarm_triggered` Home Assistant event when the alarm time is reached
- an `esphome.media_playback_failed` Home Assistant event when media starts and drops out quickly
- API actions:
  - `esphome.esp32_smart_clock_show_message`
  - `esphome.esp32_smart_clock_clear_message`

Important limitations:

- This hardware has a speaker only, not a microphone. It can play voice/TTS sent from Home Assistant, but it cannot listen for voice commands unless you add an I2S microphone.
- Wi-Fi music playback is through Home Assistant/ESPHome as a network media player. It is not a native Chromecast, AirPlay, Spotify Connect, or DLNA speaker.
- ESPHome does not expose media stream size before playback starts, so oversized streams cannot be rejected early. Fast playback failures show `AUDIO ERR` on the display and fire `esphome.media_playback_failed`.
- Changing the `Speaker` media-player volume plays a short local beep so you can hear the effective level immediately.
- For normal personalized devices, update from local ESPHome YAML by USB or by IP. That path preserves `secrets.yaml` and local YAML edits.
- The disabled-by-default `Firmware Update` entity checks public GitHub release firmware from the raw GitHub `firmware-latest` branch. Public release firmware is built with `secrets.example.yaml`, not your private `secrets.yaml`.
- The alarm trigger sets the matrix to `ALARM` and fires an `esphome.alarm_triggered` event. Use a Home Assistant automation to play TTS or `media_player.play_media` on the `Speaker` entity.
- To allow the device to fire Home Assistant events, open the ESPHome integration device settings in Home Assistant and enable "Allow the device to perform Home Assistant actions".
- The ESPHome config uses the Google Font `Noto Sans Hebrew`, so first compile needs internet access from the ESPHome builder.
- The BMP280 address is set near the top of `esphome-smart-clock.yaml` as `bmp280_address`. Most combo boards use `0x77`, but some use `0x76`.

## Home Assistant Examples

Show a message:

```yaml
action: esphome.esp32_smart_clock_show_message
data:
  message: "GOOD MORNING"
```

Clear the message so the clock/sensors show again:

```yaml
action: esphome.esp32_smart_clock_clear_message
```

Send TTS to the speaker:

```yaml
action: tts.speak
target:
  entity_id: tts.home_assistant_cloud
data:
  media_player_entity_id: media_player.esp32_smart_clock_speaker
  message: "Wake up"
```

Calendar agenda on the display and speaker:



Use this blueprint when you want a morning agenda at a fixed time, a dashboard
button that reads today's events on demand, or both. See
[Calendar And Announcements](Calendar-And-Announcements.md) for the full setup.

Alarm event automation example:

```yaml
alias: ESP32 smart clock alarm voice
triggers:
  - trigger: event
    event_type: esphome.alarm_triggered
actions:
  - action: tts.speak
    target:
      entity_id: tts.home_assistant_cloud
    data:
      media_player_entity_id: media_player.esp32_smart_clock_speaker
      message: "Wake up"
```

Media playback failure notification example:

```yaml
alias: ESP32 smart clock audio failed
triggers:
  - trigger: event
    event_type: esphome.media_playback_failed
actions:
  - action: persistent_notification.create
    data:
      title: ESP32 smart clock audio failed
      message: "The stream stopped quickly. Use 16 kHz mono or a smaller stream."
```

GitHub public firmware update check:

The easiest notification-only setup is the Home Assistant blueprint:



After import, select `update.esp32_smart_clock_firmware_update`, choose the
check time, and save the automation. Leave automatic install disabled for a
normal personalized clock.

The same notification automation is also available as `docs/home-assistant-auto-update.yaml`
if you prefer to paste YAML manually.

```yaml
alias: ESP32 smart clock GitHub firmware update check
triggers:
  - trigger: time
    at: "03:15:00"
actions:
  - action: homeassistant.update_entity
    target:
      entity_id: update.esp32_smart_clock_firmware_update
  - delay: "00:00:10"
  - condition: state
    entity_id: update.esp32_smart_clock_firmware_update
    state: "on"
  - action: persistent_notification.create
    data:
      title: ESP32 smart clock firmware update
      message: "A public GitHub release is available. For a personalized clock, update from your local ESPHome YAML by IP."
mode: single
```

Why this is notification-only by default:

- `secrets.yaml` is used at compile time. A public GitHub binary cannot read your
  local private secrets during install.
- Local YAML edits are also compile-time. A public GitHub binary replaces them.
- Runtime Home Assistant controls use ESPHome restore settings where possible,
  but compile-time Wi-Fi/API/config still comes from the firmware binary.

For normal updates, use:

```powershell
esphome upload esphome-smart-clock.yaml --device 192.168.1.99
```

How the GitHub update works:

```mermaid
flowchart TD
  A["GitHub release is created"] --> B["Release publishes normal downloadable assets"]
  B --> C["Workflow updates the firmware-latest branch"]
  C --> D["Firmware Update entity reads firmware-manifest.json from raw GitHub"]
  D --> E{"Newer version?"}
  E -->|"No"| F["Entity stays idle"]
  E -->|"Yes"| G["Entity turns on in Home Assistant"]
  G --> H["Blueprint automation runs at the selected time"]
  H --> I["Automation creates a notification by default"]
  I --> J["User updates local YAML by IP for personalized firmware"]
  J --> K["ESPHome compiles with local secrets.yaml and uploads OTA"]
```

Notes:

- The public GitHub update entity is disabled by default in new firmware. Enable
  it only if you intentionally want to test public release binaries.
- The update entity uses the `firmware-latest` branch, which is updated only after the release workflow builds and publishes a release.
- The raw GitHub update channel avoids GitHub release-download redirects with large HTTP headers, which can overflow the ESP32 HTTP client buffer.
- The blueprint notifies only by default. It installs only if you explicitly
  enable public binary install in the blueprint options.
- Use `esphome-smart-clock.ota.bin` for this path. The factory binary is only
  for USB/recovery flashing.

Notification-only GitHub firmware update check:

```yaml
alias: ESP32 smart clock firmware update available
triggers:
  - trigger: state
    entity_id: update.esp32_smart_clock_firmware_update
    to: "on"
actions:
  - action: persistent_notification.create
    data:
      title: ESP32 smart clock firmware update
      message: "A new GitHub release is ready. Open the Firmware Update entity to install it."
mode: single
```

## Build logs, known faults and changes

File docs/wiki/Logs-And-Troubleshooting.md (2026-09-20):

# Logs And Troubleshooting

Start with logs. They will tell you if Wi-Fi, I2C sensors, display, or audio are failing.

## Log Levels

ESPHome log levels, from quiet to noisy:

- `NONE` disables logs for that tag.
- `ERROR` shows only errors.
- `WARN` shows warnings and errors.
- `INFO` shows normal boot, Wi-Fi, API, and status messages.
- `DEBUG` shows detailed component behavior and is useful while debugging.
- `VERBOSE` and `VERY_VERBOSE` are very noisy and should only be used briefly.

Log levels are compiled into the firmware from `esphome-smart-clock.yaml`. If you change them, compile and upload again.

Global level:

```yaml
logger:
  level: INFO
```

Per-module levels:

```yaml
logger:
  level: DEBUG
  logs:
    wifi: INFO
    api: INFO
    sensor: INFO
    audio: DEBUG
    i2s_audio.speaker: DEBUG
    speaker: DEBUG
    speaker_media_player: DEBUG
    media_player: DEBUG
    ring_buffer: DEBUG
```

Important rule: a module cannot be more detailed than the global level. For example, if `logger.level` is `INFO`, ESPHome will reject `audio: DEBUG`. Set the global level to `DEBUG`, then keep noisy modules such as `wifi`, `api`, and `sensor` at `INFO`.

## View Logs Over USB

Connect the ESP32 by USB and run:

```powershell
cd C:\workspace\esp32_smart_clock
esphome logs esphome-smart-clock.yaml
```

If ESPHome asks for a port, choose the ESP32 COM port.

You can also force a specific COM port:

```powershell
esphome logs esphome-smart-clock.yaml --device COM5
```

Replace `COM5` with your real port from Windows Device Manager.

To upload and immediately keep the log open:

```powershell
esphome run esphome-smart-clock.yaml --device COM5
```

Use this when you need boot logs from the first seconds after flashing.

## View Logs Over Wi-Fi

After the device is already online:

```powershell
cd C:\workspace\esp32_smart_clock
esphome logs esphome-smart-clock.yaml --device OTA
```

If OTA discovery does not find the device, use the IP address:

```powershell
esphome logs esphome-smart-clock.yaml --device 192.168.1.99
```

You can also upload by IP and keep the log open:

```powershell
esphome run esphome-smart-clock.yaml --device 192.168.1.99
```

In Home Assistant, you can also open the ESPHome device and use **Logs**.

If OTA logs do not connect, use USB logs first. OTA logs only work after Wi-Fi and the ESPHome API are already connected.

## Useful Module Tags

For audio noise or playback problems, enable:

```yaml
logger:
  level: DEBUG
  logs:
    audio: DEBUG
    i2s_audio.speaker: DEBUG
    speaker: DEBUG
    speaker_media_player: DEBUG
    media_player: DEBUG
    ring_buffer: DEBUG
    wifi: INFO
    api: INFO
```

Then start playback and copy the log lines from a few seconds before playback starts until a few seconds after the noise starts. Useful lines include tags like `[audio]`, `[i2s_audio.speaker]`, `[speaker_media_player]`, and `[ring_buffer]`.

The normal firmware keeps audio logging at `INFO` for daily use. DEBUG audio logging is useful for diagnosis, but it creates more serial output and can steal CPU time while streaming.

## Music Assistant Playback Fails

If playback starts and then logs this:

```text
[E][i2s_audio.speaker]: Not enough memory
```

the ESP32 ran out of runtime RAM while trying to feed the I2S speaker. This was reproduced when testing a 22.05 kHz audio path, so the firmware was returned to the stable 16 kHz mono path.

Current expected startup line:

```text
Media playback started: media_pipeline=WAV 16000Hz mono, i2s=right stand_msb 16bit, buffer=500ms, timeout=250ms
```

If a media stream stops very quickly after starting, the clock shows `AUDIO ERR` and fires the Home Assistant event `esphome.media_playback_failed`. Use that event for notifications or automations. ESPHome does not expose stream size/bitrate before playback starts, so the firmware cannot reject large streams before trying them.

For Wi-Fi problems, use:

```yaml
logger:
  level: DEBUG
  logs:
    wifi: DEBUG
    api: INFO
```

For sensor problems, use:

```yaml
logger:
  level: DEBUG
  logs:
    i2c: DEBUG
    sensor: DEBUG
    aht10: DEBUG
    bmp280: DEBUG
```

For normal daily use, prefer `INFO` or reduce the audio modules back to `INFO` after debugging. DEBUG logging adds more serial output and can slightly increase CPU and flash usage.

## Sensors Show No Data

Look for I2C scan lines in the logs at boot.

Expected addresses:

```text
AHT20: 0x38
BMP280: 0x76 or 0x77
```

If no I2C devices are found:

- Check sensor VCC is connected to ESP32 `3V3`.
- Check GND is common with the ESP32.
- Check SDA is GPIO21.
- Check SCL is GPIO22.
- Keep I2C wires short.

If AHT20 works but BMP280 does not, change the BMP280 address near the top of `esphome-smart-clock.yaml`:

```yaml
substitutions:
  bmp280_address: "0x76"
```

Then compile and upload again.

## Common Existing Notes

- If MAX7219 text is mirrored or broken in the PlatformIO test, change `HARDWARE_TYPE` in `src/main.cpp`:
  - `MD_MAX72XX::FC16_HW`
  - `MD_MAX72XX::PAROLA_HW`
  - `MD_MAX72XX::GENERIC_HW`
- If you have only one 8x8 MAX7219 module, change `MAX_DEVICES` from `4` to `1` in `src/main.cpp`, and `num_chips` from `4` to `1` in `esphome-smart-clock.yaml`.
- If BMP280 is not found, check whether the board address is `0x76` or `0x77`. The PlatformIO firmware tries both. The ESPHome YAML uses `bmp280_address` near the top of the file; change it to the address shown by the I2C scan if needed.
- If AHT20 logs communication errors in ESPHome, keep `variant: AHT20` and check that the module is powered from 3V3 with SDA/SCL on GPIO21/GPIO22.
- If audio is noisy, keep I2S wires short and add bulk capacitance near the amplifier.

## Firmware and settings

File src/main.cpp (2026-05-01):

#include <Arduino.h>
#include <Wire.h>
#include <SPI.h>
#include <Adafruit_AHTX0.h>
#include <Adafruit_BMP280.h>
#include <MD_MAX72xx.h>
#include <driver/i2s.h>
#include <math.h>
#include "hebrew_display_5x7.h"

// =========================
// Pin map - ESP32 30 pin
// =========================
// AHT20 + BMP280 I2C
#define I2C_SDA 21
#define I2C_SCL 22

// MAX7219 LED matrix
#define MAX7219_DIN 23
#define MAX7219_CLK 18
#define MAX7219_CS  5

// NS4168 I2S amplifier
#define I2S_DOUT 25
#define I2S_BCLK 26
#define I2S_LRC  27

// =========================
// MAX7219 settings
// =========================
#define HARDWARE_TYPE MD_MAX72XX::FC16_HW
#define MAX_DEVICES 4  // 4 modules = 8x32 display. Change to 1 for one 8x8 module.

MD_MAX72XX mx = MD_MAX72XX(HARDWARE_TYPE, MAX7219_DIN, MAX7219_CLK, MAX7219_CS, MAX_DEVICES);

// =========================
// Sensors
// =========================
Adafruit_AHTX0 aht;
Adafruit_BMP280 bmp(&Wire);

bool ahtOk = false;
bool bmpOk = false;

// =========================
// I2S audio
// =========================
#define I2S_PORT I2S_NUM_0
#define SAMPLE_RATE 16000

void initI2S() {
  i2s_config_t i2s_config = {
    .mode = (i2s_mode_t)(I2S_MODE_MASTER | I2S_MODE_TX),
    .sample_rate = SAMPLE_RATE,
    .bits_per_sample = I2S_BITS_PER_SAMPLE_16BIT,
    .channel_format = I2S_CHANNEL_FMT_ONLY_LEFT,
    .communication_format = I2S_COMM_FORMAT_STAND_I2S,
    .intr_alloc_flags = 0,
    .dma_buf_count = 8,
    .dma_buf_len = 256,
    .use_apll = false,
    .tx_desc_auto_clear = true,
    .fixed_mclk = 0
  };

  i2s_pin_config_t pin_config = {
    .bck_io_num = I2S_BCLK,
    .ws_io_num = I2S_LRC,
    .data_out_num = I2S_DOUT,
    .data_in_num = I2S_PIN_NO_CHANGE
  };

  esp_err_t err = i2s_driver_install(I2S_PORT, &i2s_config, 0, NULL);
  if (err != ESP_OK) {
    Serial.printf("I2S driver install failed: %d\n", err);
    return;
  }

  err = i2s_set_pin(I2S_PORT, &pin_config);
  if (err != ESP_OK) {
    Serial.printf("I2S set pin failed: %d\n", err);
    return;
  }

  i2s_zero_dma_buffer(I2S_PORT);
  Serial.println("I2S OK");
}

void playTone(int freq, int durationMs, int amplitude = 2500) {
  int totalSamples = (SAMPLE_RATE * durationMs) / 1000;
  int16_t sampleBuffer[256];

  for (int i = 0; i < totalSamples; i += 256) {
    int chunk = min(256, totalSamples - i);

    for (int j = 0; j < chunk; j++) {
      float t = (float)(i + j) / SAMPLE_RATE;
      sampleBuffer[j] = (int16_t)(amplitude * sinf(2.0f * PI * freq * t));
    }

    size_t bytesWritten = 0;
    i2s_write(I2S_PORT, sampleBuffer, chunk * sizeof(int16_t), &bytesWritten, portMAX_DELAY);
  }

  i2s_zero_dma_buffer(I2S_PORT);
}

// =========================
// Display helpers
// =========================
// Hebrew text rendering and scrolling is handled by hebrew_display_5x7.h

void i2cScan() {
  Serial.println("I2C scan start...");
  byte count = 0;
  for (byte address = 1; address < 127; address++) {
    Wire.beginTransmission(address);
    byte error = Wire.endTransmission();
    if (error == 0) {
      Serial.printf("I2C device found at 0x%02X\n", address);
      count++;
    }
  }
  Serial.printf("I2C scan done. Found %d device(s).\n", count);
}

void initSensors() {
  delay(250);

  ahtOk = aht.begin(&Wire);
  Serial.println(ahtOk ? "AHT20 OK" : "AHT20 NOT FOUND");

  bmpOk = bmp.begin(0x76);
  if (!bmpOk) {
    bmpOk = bmp.begin(0x77);
  }

  if (bmpOk) {
    Serial.println("BMP280 OK");
    bmp.setSampling(Adafruit_BMP280::MODE_NORMAL,
                    Adafruit_BMP280::SAMPLING_X2,
                    Adafruit_BMP280::SAMPLING_X16,
                    Adafruit_BMP280::FILTER_X16,
                    Adafruit_BMP280::STANDBY_MS_500);
  } else {
    Serial.println("BMP280 NOT FOUND");
  }
}

void setup() {
  Serial.begin(115200);
  delay(1000);
  Serial.println();
  Serial.println("ESP32 Smart Clock hardware test starting...");

  Wire.begin(I2C_SDA, I2C_SCL);
  i2cScan();

  mx.begin();
  mx.control(MD_MAX72XX::INTENSITY, 3); // brightness 0-15
  mx.clear();
  scrollMixedTextRTL(mx, "שלום...", 45);

  initSensors();
  initI2S();
  playTone(1000, 150);
}

void loop() {
  float tempAht = NAN;
  float humidity = NAN;
  float tempBmp = NAN;
  float pressure = NAN;

  if (ahtOk) {
    sensors_event_t humEvent, tempEvent;
    aht.getEvent(&humEvent, &tempEvent);
    tempAht = tempEvent.temperature;
    humidity = humEvent.relative_humidity;
  }

  if (bmpOk) {
    tempBmp = bmp.readTemperature();
    pressure = bmp.readPressure() / 100.0f;
  }

  Serial.println("----------------------");
  if (ahtOk) {
    Serial.printf("AHT20 temp: %.2f C\n", tempAht);
    Serial.printf("AHT20 humidity: %.2f %%\n", humidity);
  }
  if (bmpOk) {
    Serial.printf("BMP280 temp: %.2f C\n", tempBmp);
    Serial.printf("BMP280 pressure: %.2f hPa\n", pressure);
  }

  String msg;
  if (ahtOk) {
    msg = "טמפ " + String(tempAht, 1) + "C לחות " + String(humidity, 0) + "%";
  } else if (bmpOk) {
    msg = "טמפ " + String(tempBmp, 1) + "C לחץ " + String(pressure, 0) + "hPa";
  } else {
    msg = "אין חיישנים";
  }

  scrollMixedTextRTL(mx, msg, 45);
  playTone(1200, 80);
  delay(3000);
}

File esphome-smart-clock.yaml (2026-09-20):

substitutions:
  device_name: esp32-smart-clock
  friendly_name: ESP32 Smart Clock
  firmware_version: "0.1.0-beta.14"
  github_repo: NirBY/ESP32_Smart_Clock
  github_release_manifest_url: "https://raw.githubusercontent.com/${github_repo}/firmware-latest/firmware-manifest.json"
  bmp280_address: "0x77"

esphome:
  name: ${device_name}
  friendly_name: ${friendly_name}
  project:
    name: nirby.esp32_smart_clock
    version: "${firmware_version}"
  build_path: C:/Users/nirbe/.esphome/build/${device_name}
  devices:
    - id: display_device
      name: "ESP32 Smart Clock Display"
    - id: alarm_device
      name: "ESP32 Smart Clock Alarm"
    - id: audio_device
      name: "ESP32 Smart Clock Audio"
    - id: system_device
      name: "ESP32 Smart Clock System"
    - id: sensor_device
      name: "ESP32 Smart Clock Sensors"
  includes:
    - src/system_health.h
  on_boot:
    priority: -100
    then:
      - lambda: |-
          id(time_sync_retry_active) = true;
          id(boot_low_power_seen) = smart_clock_booted_from_brownout();
          if (!isnan(id(display_brightness).state)) {
            id(matrix_display).intensity((uint8_t) id(display_brightness).state);
          }
      - component.update: matrix_display

esp32:
  board: esp32dev
  framework:
    type: esp-idf
    advanced:
      minimum_chip_revision: "3.1"
      sram1_as_iram: true

logger:
  # DEBUG logging keeps more strings/buffers active and can steal CPU while audio
  # is playing. INFO still keeps useful boot and troubleshooting messages.
  level: INFO
  logs:
    audio: INFO
    api: INFO
    component: INFO
    i2s_audio.speaker: INFO
    media_player: INFO
    ring_buffer: WARN
    sensor: INFO
    settings: INFO
    speaker: INFO
    speaker_media_player: INFO
    time: INFO
    wifi: INFO
    aht10: WARN
    bmp280: WARN

api:
  encryption:
    key: !secret api_encryption_key
  # Home Assistant is normally the only API client. Smaller queues/connections
  # reduce RAM pressure on the non-PSRAM ESP32.
  max_connections: 2
  max_send_queue: 4
  actions:
    - action: show_message
      variables:
        message: string
      then:
        - lambda: |-
            const float seconds = isnan(id(text_message_seconds).state) ? 10.0f : id(text_message_seconds).state;
            ESP_LOGI("settings", "Screen message changed to '%s' for %.0f seconds", message.c_str(), seconds);
            id(text_message) = message;
            id(text_message_until) = message.empty() ? 0 : millis() + (uint32_t) (seconds * 1000.0f);
        - component.update: matrix_display
    - action: clear_message
      then:
        - lambda: |-
            ESP_LOGI("settings", "Screen message cleared");
            id(text_message).clear();
            id(text_message_until) = 0;
        - component.update: matrix_display

ota:
  - platform: esphome
  - platform: http_request

http_request:
  # GitHub release asset URLs redirect to long signed URLs. Keep redirects on
  # and use a larger receive buffer so update checks do not fail on Location.
  follow_redirects: true
  redirect_limit: 5
  timeout: 30s
  buffer_size_rx: 4096
  buffer_size_tx: 512

wifi:
  id: wifi_component
  ssid: !secret wifi_ssid
  password: !secret wifi_password
  fast_connect: true
  on_connect:
    - lambda: |-
        ESP_LOGI("time", "Wi-Fi connected; requesting immediate time synchronization");
        id(time_sync_retry_active) = true;
        id(last_time_sync_retry_ms) = 0;
        id(time_sync_retry_count) = 0;
    - script.execute: request_time_sync
  on_disconnect:
    - lambda: |-
        ESP_LOGW("time", "Wi-Fi disconnected; time synchronization will retry after reconnect");
        id(time_sync_retry_active) = true;
  ap:
    ssid: "${friendly_name} Fallback"
    password: !secret fallback_ap_password
    # Open the recovery portal after 90 seconds without a Wi-Fi connection.
    ap_timeout: 90s

captive_portal:
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

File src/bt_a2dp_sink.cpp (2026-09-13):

#include <Arduino.h>
#include <esp_arduino_version.h>
#if ESP_ARDUINO_VERSION_MAJOR >= 3
#include <ESP_I2S.h>
#else
#include <driver/i2s.h>
#endif
#include "BluetoothA2DPSink.h"

// NS4168 I2S amplifier
#define I2S_DOUT 25
#define I2S_BCLK 26
#define I2S_LRC 27

#if ESP_ARDUINO_VERSION_MAJOR >= 3
I2SClass i2s;
BluetoothA2DPSink a2dpSink(i2s);
#else
BluetoothA2DPSink a2dpSink;
#endif

void setup() {
  Serial.begin(115200);
  delay(500);

#if ESP_ARDUINO_VERSION_MAJOR >= 3
  i2s.setPins(I2S_BCLK, I2S_LRC, I2S_DOUT);
  if (!i2s.begin(I2S_MODE_STD, 44100, I2S_DATA_BIT_WIDTH_16BIT,
                 I2S_SLOT_MODE_STEREO, I2S_STD_SLOT_BOTH)) {
    Serial.println("Failed to initialize I2S!");
  }
#else
  // PlatformIO espressif32 uses Arduino-ESP32 2.x. Let ESP32-A2DP
  // initialize its legacy I2S output (44.1 kHz, 16-bit stereo by default).
  const i2s_pin_config_t pins = {
      .mck_io_num = I2S_PIN_NO_CHANGE,
      .bck_io_num = I2S_BCLK,
      .ws_io_num = I2S_LRC,
      .data_out_num = I2S_DOUT,
      .data_in_num = I2S_PIN_NO_CHANGE,
  };
  a2dpSink.set_pin_config(pins);
#endif

  a2dpSink.start("ESP32 Smart Clock");

  Serial.println("Bluetooth speaker ready.");
  Serial.println("Pair Android, iPhone, or PC with: ESP32 Smart Clock");
}

void loop() {
  delay(1000);
}

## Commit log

2026-04-24 Fix display brightness control
    [esphome-smart-clock.yaml]
2026-04-24 Improve sensor fallback handling
2026-04-24 Update display docs and volume feedback.
    Document the display priority rules, show only temperature and humidity on the matrix, and add an audible volume-change beep for easier speaker setup.
    Made-with: Cursor
2026-04-24 Fix volume beep code generation.
    Defer the on-volume beep through a pending flag so ESPHome can generate the media file before the playback action references it.
    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
    [esphome-smart-clock.yaml]
2026-04-25 Update smart clock audio and documentation.
    Stabilize the NS4168 I2S configuration, expand ESPHome display controls, and move detailed project docs into wiki-ready pages.
    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
    [esphome-smart-clock.yaml]
2026-05-01 Improve matrix text and sensor display
2026-05-01 Fix Hebrew matrix text rendering
    [esphome-smart-clock.yaml, main.cpp]
2026-05-09 Add system alerts and design assets
    [AHT20+BMP280 case_1.stl, AHT20+BMP280 case_2.stl, ESP32+dev+Kit+v1.stl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]
2026-05-09 Fix firmware update channel publishing
    [esphome-smart-clock.yaml]
2026-05-09 Keep only final STL models
    [AHT20+BMP280 case_1.stl, AHT20+BMP280 case_2.stl, ESP32+dev+Kit+v1.stl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]
2026-09-13 Fix Bluetooth I2S compatibility with Arduino ESP32 2.x and 3.x
    [bt_a2dp_sink.cpp]
2026-10-23 Release beta.15 timer updates, final enclosure and publication assets
2026-10-23 Add verified Ender-3 V3 KE print configuration and insert pause
2026-10-24 Refresh public guides, MCP setup and wiring; remove print pause
2026-10-24 Show both USB-C connectors explicitly in wiring diagram
2026-10-24 Draw direct USB-C power distribution separate from ESP32 3V3
2026-10-24 Remove nonexistent U2 and document direct MAX7219 wiring
2026-10-24 Connect USB-C power visibly to all loads in main wiring diagram
